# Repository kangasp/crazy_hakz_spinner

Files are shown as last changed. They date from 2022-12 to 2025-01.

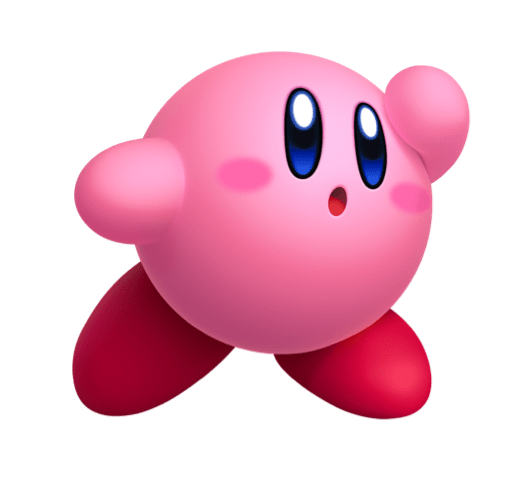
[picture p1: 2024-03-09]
tools/binaries/test_images/kirby.png

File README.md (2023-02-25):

# crazy_hakz_spinner
Spinning LEDs

### Notes from 2-24-23
--------------------------------------------
The footprint for the through beam sensor is wrong - pins 3 and 4 should be switched.
Pin 4 is actually ground / emiter, and pin 3 is actually the collector / vcc.

The through beem should sensor should not be pulled up to VCC - which is 5v.  It should 
be pulled up to 3.3v.

The level shifter should be moved - as it's too close to the mounting bracket... maybe get a bigger one.

Consider moving the positional / counter through beam to the edge.

Consider adding a testpoint header.

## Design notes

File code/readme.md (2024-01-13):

To develop here do these things.

Get the esp-idf framework.  Follow this:
https://docs.espressif.com/projects/esp-idf/en/latest/esp32/get-started/index.html

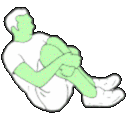
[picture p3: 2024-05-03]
cool_pics/party/png/party7.png

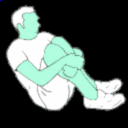
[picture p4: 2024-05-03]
cool_pics/party/bmp/party6.bmp

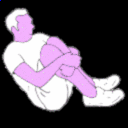
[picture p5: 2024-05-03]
cool_pics/party/bmp/party11.bmp

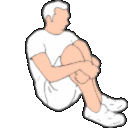
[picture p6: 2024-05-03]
cool_pics/party/png/party1.png

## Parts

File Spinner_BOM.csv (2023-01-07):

Index | Quantity | Part Number | Manufacturer Part Number | Description | Customer Reference | Available | Backorder | Unit Price | Extended Price USD
1 | 1 | 1528-2883-ND | 4172 | HUZZAH32 - ESP32 BREAKOUT BOARD |  | 1 | 0 | 13.50000 | 13.50
2 | 1 | AP63205WU-7DICT-ND | AP63205WU-7 | IC REG BUCK 5V 2A TSOT26 |  | 1 | 0 | 0.91000 | 0.91
3 | 6 | 36-2460-ND | 2460 | BATT HOLDER AA 1 CELL PC PIN |  | 6 | 0 | 1.30000 | 7.80
4 | 1 | EG5810CT-ND | 500ASSP1SM6QE | SWITCH SLIDE SPDT 3A 120V |  | 1 | 0 | 4.90000 | 4.90
5 | 1 | 3565-RS0102YH8CT-ND | RS0102YH8 | IC TRANSLATOR BIDIR SOT23-8 |  | 1 | 0 | 0.67000 | 0.67
6 | 2 | NSI45020AT1GOSCT-ND | NSI45020AT1G | IC LED DRIVER LINEAR SOD-123 |  | 2 | 0 | 0.57000 | 1.14
7 | 3 | RMCF0805JT3K30CT-ND | RMCF0805JT3K30 | RES 3.3K OHM 5% 1/8W 0805 |  | 3 | 0 | 0.10000 | 0.30
8 | 1 | CV201210-4R7KCT-ND | CV201210-4R7K | FIXED IND 4.7UH 30MA 1 OHM SMD |  | 1 | 0 | 0.10000 | 0.10
9 | 1 | 1276-1096-1-ND | CL21A106KOQNNNE | CAP CER 10UF 16V X5R 0805 |  | 1 | 0 | 0.10000 | 0.10
10 | 2 | 1276-6460-1-ND | CL21A226MQQNNNG | CAP CER 22UF 6.3V X5R 0805 |  | 2 | 0 | 0.13000 | 0.26
11 | 50 | 1276-1099-1-ND | CL21B104KACNNNC | CAP CER 0.1UF 25V X7R 0805 |  | 50 | 0 | 0.02020 | 1.01

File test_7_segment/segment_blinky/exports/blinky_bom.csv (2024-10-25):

Comment | Designator | Footprint | JLCPCDB Part #
LED | D7,D6,D42,D36,D24,D14,D26,D50,D8,D15,D59,D22,D55,D39,D44,D48,D9,D46,D11,D4,D49,D38,D53,D54,D21,D56,D17,D28,D45,D43,D47,D27,D60,D57,D30,D31,D35,D34,D32,D58,D37,D12,D2,D33,D51,D19,D29,D52,D13,D5,D41,D23,D18,D25,D16,D40,D20,D3 | SK9822-hakz | C2909059

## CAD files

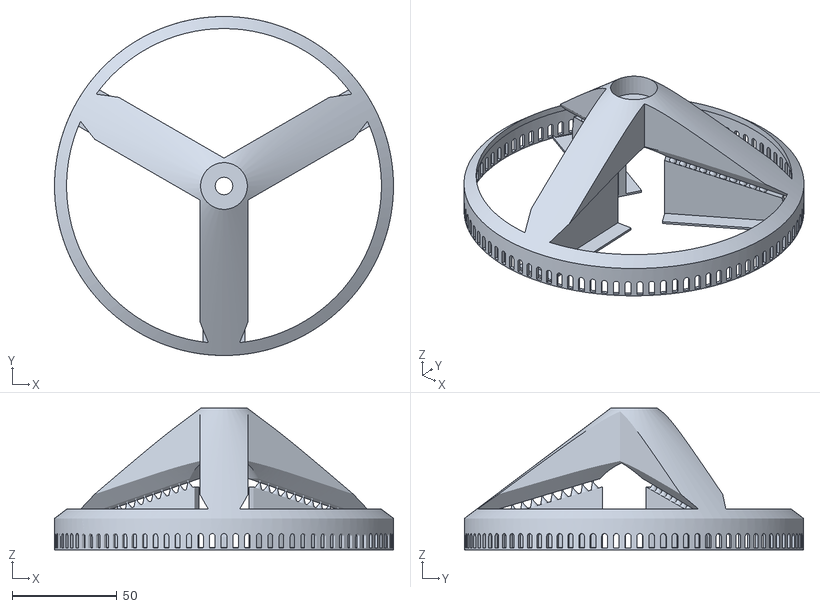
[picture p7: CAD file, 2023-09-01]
stl/crown_w_supports.stl
161.5 x 161.5 x 67.4

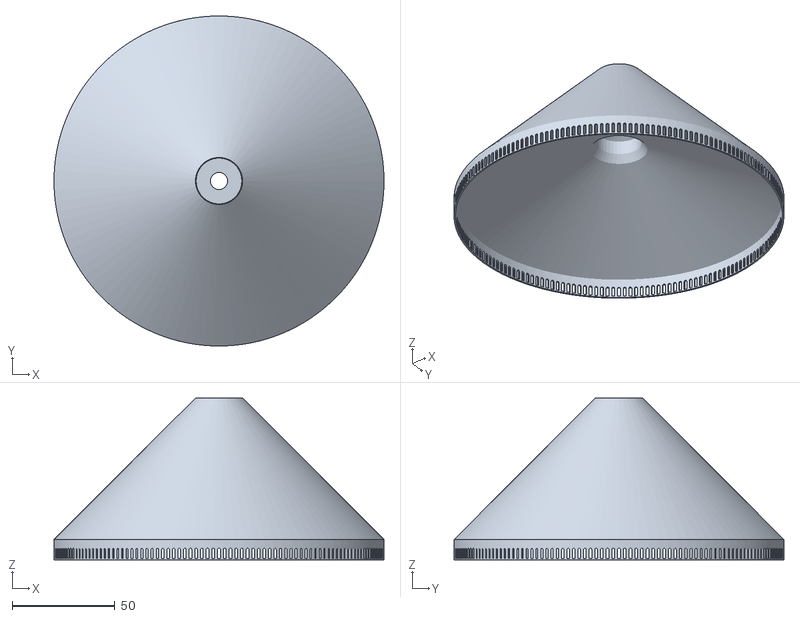
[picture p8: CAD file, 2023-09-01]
stl/crown_01.stl
160.8 x 160.8 x 78.9

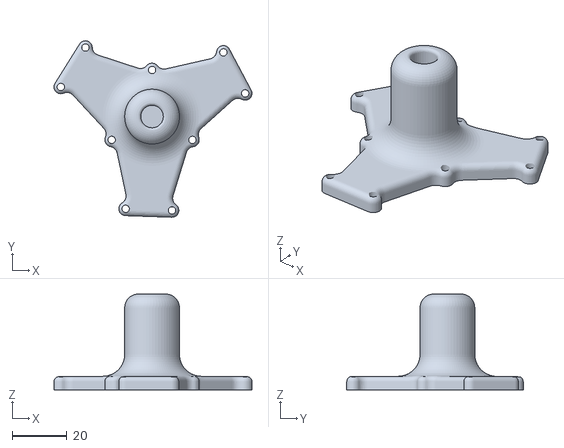
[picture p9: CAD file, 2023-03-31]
stl/rod_bracket_01.stl
72.2 x 64.4 x 35.0

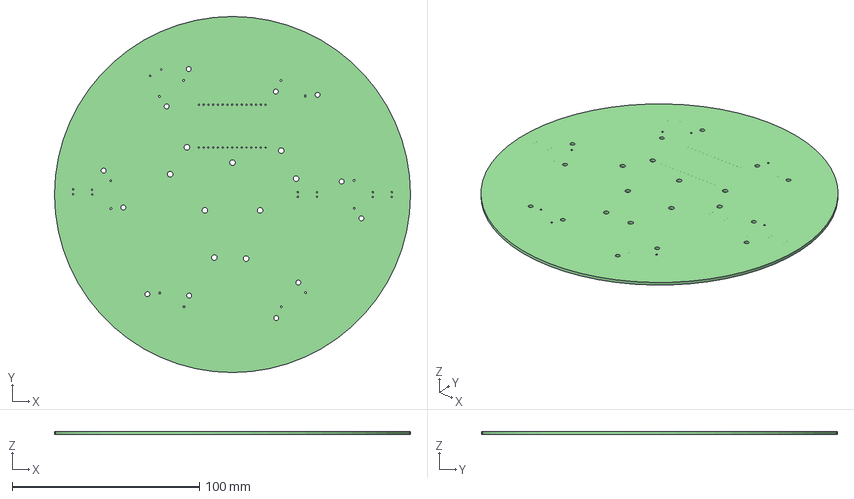
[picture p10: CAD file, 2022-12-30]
stl/spinner.step
190.0 x 190.0 x 1.60 mm

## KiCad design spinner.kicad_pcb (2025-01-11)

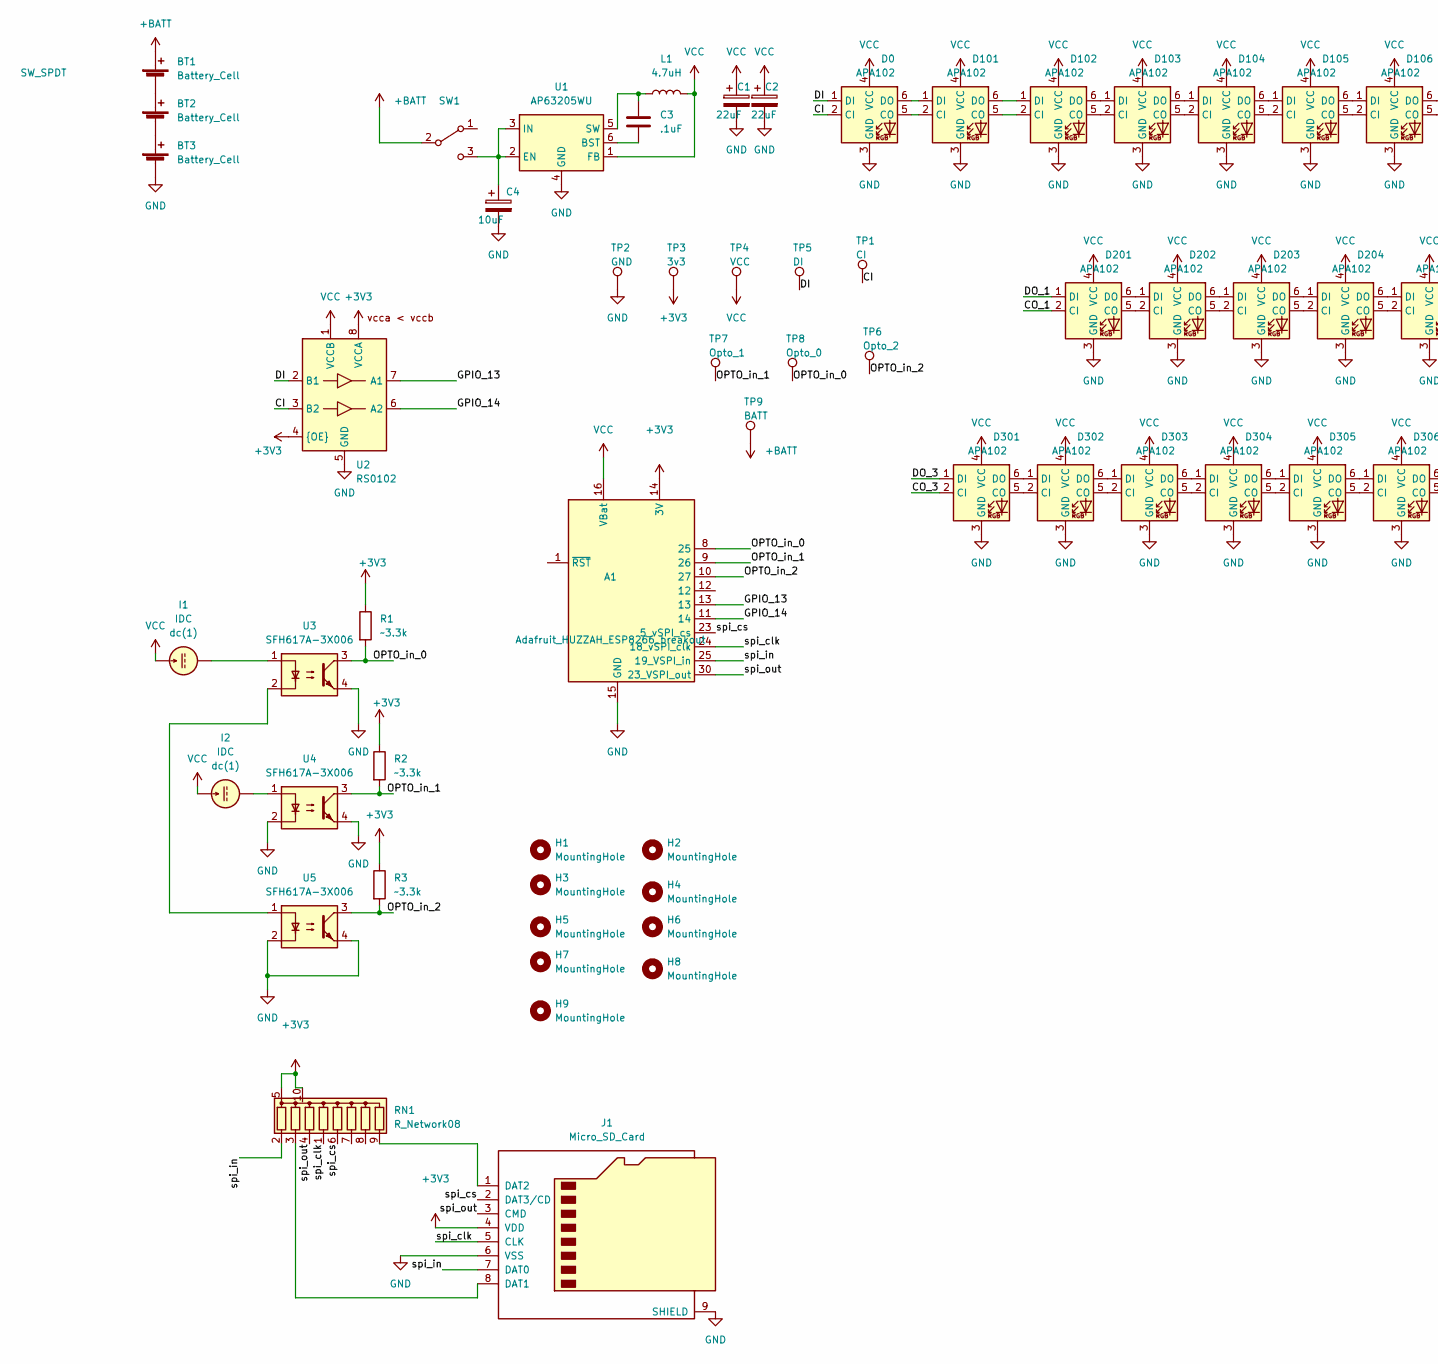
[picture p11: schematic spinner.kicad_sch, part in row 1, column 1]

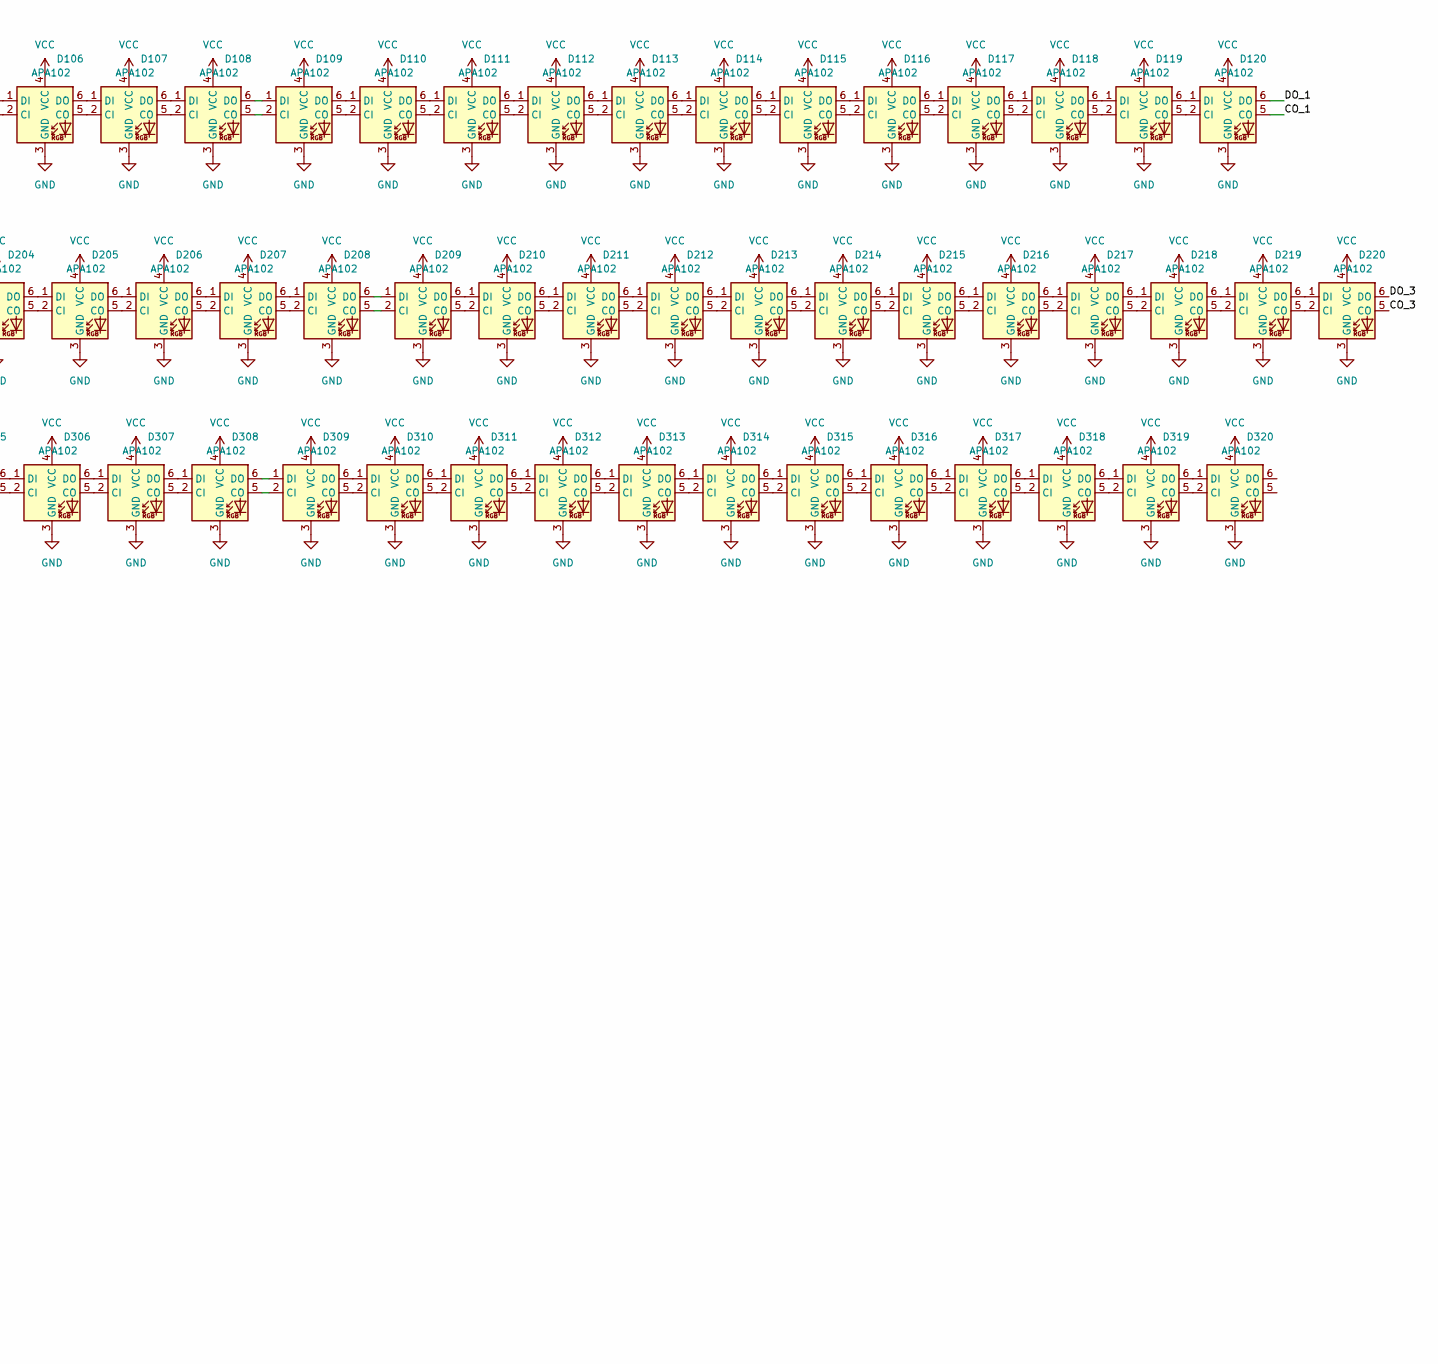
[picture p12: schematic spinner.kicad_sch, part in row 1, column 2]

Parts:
A1: Adafruit_HUZZAH_ESP8266_breakout; huzz_hakz
BT1, BT2, BT3: Battery_Cell; Spinner_BatteryHolder_Keystone_2460_1xAA
C1, C2: 22uF; C_0805_2012Metric_Pad1.18x1.45mm_HandSolder
C3: .1uF; C_0805_2012Metric_Pad1.18x1.45mm_HandSolder
C4: 10uF; C_0805_2012Metric_Pad1.18x1.45mm_HandSolder
D0, D101, D102, D103, D104, D105, D106, D107, D108, D109, D110, D111, D112, D113, D114, D115, D116, D117, D118, D119, D120, D201, D202, D203, D204, D205, D206, D207, D208, D209, D210, D211, D212, D213, D214, D215, D216, D217, D218, D219, D220, D301, D302, D303, D304, D305, D306, D307, D308, D309, D310, D311, D312, D313, D314, D315, D316, D317, D318, D319, D320: APA102; SK9822-hakz
H1, H2, H3, H4, H5, H6, H7, H8, H9: MountingHole; MountingHole_3mm
I1, I2: IDC; D_SOD-123
J1: Micro_SD_Card; microSD_HC_Hirose_DM3AT-SF-PEJM5
L1: 4.7uH; L_0805_2012Metric_Pad1.05x1.20mm_HandSolder
R1, R2, R3: ~3.3k; R_0805_2012Metric_Pad1.20x1.40mm_HandSolder
RN1: R_Network08; R_Array_Convex_5x1206
SW1: SW_SPDT; SW_SPDT_CK-JS102011SAQN
TP1: CI; TestPoint_Pad_D2.5mm
TP2: GND; TestPoint_Pad_D2.5mm
TP3: 3v3; TestPoint_Pad_D2.5mm
TP4: VCC; TestPoint_Pad_D2.5mm
TP5: DI; TestPoint_Pad_D2.5mm
TP6: Opto_2; TestPoint_Pad_D2.5mm
TP7: Opto_1; TestPoint_Pad_D2.5mm
TP8: Opto_0; TestPoint_Pad_D2.5mm
TP9: BATT; TestPoint_Pad_D2.5mm
U1: AP63205WU; TSOT-23-6
U2: RS0102; MSOP-8_3x3mm_P0.65mm
U3, U4: SFH617A-3X006; MULTI_PART_THRU_BEAM
U5: SFH617A-3X006; tcrt1000

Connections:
+3V3: A1.14 (3V), J1.4 (VDD), R1.1, R2.1, R3.1, RN1.5 (common), RN1.10 (common), TP3.1, U2.4 ({OE}), U2.8 (VCCA)
+BATT: BT1.1 (+), SW1.2 (B), TP9.1
/CI: D0.2 (CI), TP1.1, U2.3 (B2)
/CO_1: D120.5 (CO), D201.2 (CI)
/CO_3: D220.5 (CO), D301.2 (CI)
/DI: D0.1 (DI), TP5.1, U2.2 (B1)
/DO_1: D120.6 (DO), D201.1 (DI)
/DO_3: D220.6 (DO), D301.1 (DI)
/GPIO_13: A1.13, U2.7 (A1)
/GPIO_14: A1.11 (14), U2.6 (A2)
/OPTO_in_0: A1.8 (25), R1.2, TP8.1, U3.3
/OPTO_in_1: A1.9 (26), R2.2, TP7.1, U4.3
/OPTO_in_2: A1.10 (27), R3.2, TP6.1, U5.3
/spi_clk: A1.24 (18_vSPI_clk), J1.5 (CLK), RN1.1 (R4)
/spi_cs: A1.23 (5_vSPI_cs), J1.2 (DAT3/CD), RN1.6 (R5)
/spi_in: A1.25 (19_VSPI_in), J1.7 (DAT0), RN1.2 (R1)
/spi_out: A1.30 (23_VSPI_out), J1.3 (CMD), RN1.4 (R3)
GND: A1.15 (GND), BT3.2 (-), C1.2, C2.2, C4.2, D0.3 (GND), D101.3 (GND), D102.3 (GND), D103.3 (GND), D104.3 (GND), D105.3 (GND), D106.3 (GND), D107.3 (GND), D108.3 (GND), D109.3 (GND), D110.3 (GND), D111.3 (GND), D112.3 (GND), D113.3 (GND), D114.3 (GND), D115.3 (GND), D116.3 (GND), D117.3 (GND), D118.3 (GND), D119.3 (GND), D120.3 (GND), D201.3 (GND), D202.3 (GND), D203.3 (GND), D204.3 (GND), D205.3 (GND), D206.3 (GND), D207.3 (GND), D208.3 (GND), D209.3 (GND), D210.3 (GND), D211.3 (GND), D212.3 (GND), D213.3 (GND), D214.3 (GND), D215.3 (GND), D216.3 (GND), D217.3 (GND), D218.3 (GND), D219.3 (GND), D220.3 (GND), D301.3 (GND), D302.3 (GND), D303.3 (GND), D304.3 (GND), D305.3 (GND), D306.3 (GND), D307.3 (GND), D308.3 (GND), D309.3 (GND), D310.3 (GND), D311.3 (GND), D312.3 (GND), D313.3 (GND), D314.3 (GND), D315.3 (GND), D316.3 (GND), D317.3 (GND), D318.3 (GND), D319.3 (GND), D320.3 (GND), J1.6 (VSS), J1.9 (SHIELD), TP2.1, U1.4 (GND), U2.5 (GND), U3.4, U4.2, U4.4, U5.2, U5.4
unnamed: BT1.2 (-), BT2.1 (+)
unnamed: BT2.2 (-), BT3.1 (+)
unnamed: C3.1, L1.1, U1.5 (SW)
unnamed: C3.2, U1.6 (BST)
unnamed: C4.1, SW1.3 (C), U1.2 (EN), U1.3 (IN)
unnamed: D0.5 (CO), D101.2 (CI)
unnamed: D0.6 (DO), D101.1 (DI)
unnamed: D101.5 (CO), D102.2 (CI)
unnamed: D101.6 (DO), D102.1 (DI)
unnamed: D102.5 (CO), D103.2 (CI)
unnamed: D102.6 (DO), D103.1 (DI)
unnamed: D103.5 (CO), D104.2 (CI)
unnamed: D103.6 (DO), D104.1 (DI)
unnamed: D104.5 (CO), D105.2 (CI)
unnamed: D104.6 (DO), D105.1 (DI)
unnamed: D105.5 (CO), D106.2 (CI)
unnamed: D105.6 (DO), D106.1 (DI)
unnamed: D106.5 (CO), D107.2 (CI)
unnamed: D106.6 (DO), D107.1 (DI)
unnamed: D107.5 (CO), D108.2 (CI)
unnamed: D107.6 (DO), D108.1 (DI)
unnamed: D108.5 (CO), D109.2 (CI)
unnamed: D108.6 (DO), D109.1 (DI)
unnamed: D109.5 (CO), D110.2 (CI)
unnamed: D109.6 (DO), D110.1 (DI)
unnamed: D110.5 (CO), D111.2 (CI)
unnamed: D110.6 (DO), D111.1 (DI)
unnamed: D111.5 (CO), D112.2 (CI)
unnamed: D111.6 (DO), D112.1 (DI)
unnamed: D112.5 (CO), D113.2 (CI)
unnamed: D112.6 (DO), D113.1 (DI)
unnamed: D113.5 (CO), D114.2 (CI)
unnamed: D113.6 (DO), D114.1 (DI)
unnamed: D114.5 (CO), D115.2 (CI)
unnamed: D114.6 (DO), D115.1 (DI)
unnamed: D115.5 (CO), D116.2 (CI)
unnamed: D115.6 (DO), D116.1 (DI)
unnamed: D116.5 (CO), D117.2 (CI)
unnamed: D116.6 (DO), D117.1 (DI)
unnamed: D117.5 (CO), D118.2 (CI)
unnamed: D117.6 (DO), D118.1 (DI)
unnamed: D118.5 (CO), D119.2 (CI)
unnamed: D118.6 (DO), D119.1 (DI)
unnamed: D119.5 (CO), D120.2 (CI)
unnamed: D119.6 (DO), D120.1 (DI)
unnamed: D201.5 (CO), D202.2 (CI)
unnamed: D201.6 (DO), D202.1 (DI)
unnamed: D202.5 (CO), D203.2 (CI)
unnamed: D202.6 (DO), D203.1 (DI)
unnamed: D203.5 (CO), D204.2 (CI)
unnamed: D203.6 (DO), D204.1 (DI)
unnamed: D204.5 (CO), D205.2 (CI)
unnamed: D204.6 (DO), D205.1 (DI)
unnamed: D205.5 (CO), D206.2 (CI)
unnamed: D205.6 (DO), D206.1 (DI)
unnamed: D206.5 (CO), D207.2 (CI)
unnamed: D206.6 (DO), D207.1 (DI)
unnamed: D207.5 (CO), D208.2 (CI)
unnamed: D207.6 (DO), D208.1 (DI)
unnamed: D208.5 (CO), D209.2 (CI)
unnamed: D208.6 (DO), D209.1 (DI)
unnamed: D209.5 (CO), D210.2 (CI)
unnamed: D209.6 (DO), D210.1 (DI)
unnamed: D210.5 (CO), D211.2 (CI)
unnamed: D210.6 (DO), D211.1 (DI)
unnamed: D211.5 (CO), D212.2 (CI)
unnamed: D211.6 (DO), D212.1 (DI)
unnamed: D212.5 (CO), D213.2 (CI)
unnamed: D212.6 (DO), D213.1 (DI)
unnamed: D213.5 (CO), D214.2 (CI)
unnamed: D213.6 (DO), D214.1 (DI)
unnamed: D214.5 (CO), D215.2 (CI)
unnamed: D214.6 (DO), D215.1 (DI)
unnamed: D215.5 (CO), D216.2 (CI)
unnamed: D215.6 (DO), D216.1 (DI)
unnamed: D216.5 (CO), D217.2 (CI)
unnamed: D216.6 (DO), D217.1 (DI)
unnamed: D217.5 (CO), D218.2 (CI)
unnamed: D217.6 (DO), D218.1 (DI)
unnamed: D218.5 (CO), D219.2 (CI)
unnamed: D218.6 (DO), D219.1 (DI)
unnamed: D219.5 (CO), D220.2 (CI)
unnamed: D219.6 (DO), D220.1 (DI)
unnamed: D301.5 (CO), D302.2 (CI)
unnamed: D301.6 (DO), D302.1 (DI)
unnamed: D302.5 (CO), D303.2 (CI)
unnamed: D302.6 (DO), D303.1 (DI)
unnamed: D303.5 (CO), D304.2 (CI)
unnamed: D303.6 (DO), D304.1 (DI)
unnamed: D304.5 (CO), D305.2 (CI)
unnamed: D304.6 (DO), D305.1 (DI)
unnamed: D305.5 (CO), D306.2 (CI)
unnamed: D305.6 (DO), D306.1 (DI)
unnamed: D306.5 (CO), D307.2 (CI)
unnamed: D306.6 (DO), D307.1 (DI)
unnamed: D307.5 (CO), D308.2 (CI)
unnamed: D307.6 (DO), D308.1 (DI)
unnamed: D308.5 (CO), D309.2 (CI)
unnamed: D308.6 (DO), D309.1 (DI)
unnamed: D309.5 (CO), D310.2 (CI)
unnamed: D309.6 (DO), D310.1 (DI)
unnamed: D310.5 (CO), D311.2 (CI)
unnamed: D310.6 (DO), D311.1 (DI)
unnamed: D311.5 (CO), D312.2 (CI)
unnamed: D311.6 (DO), D312.1 (DI)
unnamed: D312.5 (CO), D313.2 (CI)
unnamed: D312.6 (DO), D313.1 (DI)
unnamed: D313.5 (CO), D314.2 (CI)
unnamed: D313.6 (DO), D314.1 (DI)
unnamed: D314.5 (CO), D315.2 (CI)
unnamed: D314.6 (DO), D315.1 (DI)
unnamed: D315.5 (CO), D316.2 (CI)
unnamed: D315.6 (DO), D316.1 (DI)
unnamed: D316.5 (CO), D317.2 (CI)
unnamed: D316.6 (DO), D317.1 (DI)
unnamed: D317.5 (CO), D318.2 (CI)
unnamed: D317.6 (DO), D318.1 (DI)
unnamed: D318.5 (CO), D319.2 (CI)
unnamed: D318.6 (DO), D319.1 (DI)
unnamed: D319.5 (CO), D320.2 (CI)
unnamed: D319.6 (DO), D320.1 (DI)
unnamed: I1.2, U3.1
unnamed: I2.2, U4.1
unnamed: J1.1 (DAT2), RN1.9 (R8)
unnamed: J1.8 (DAT1), RN1.3 (R2)
unnamed: U3.2, U5.1
VCC: A1.16 (VBat), C1.1, C2.1, D0.4 (VCC), D101.4 (VCC), D102.4 (VCC), D103.4 (VCC), D104.4 (VCC), D105.4 (VCC), D106.4 (VCC), D107.4 (VCC), D108.4 (VCC), D109.4 (VCC), D110.4 (VCC), D111.4 (VCC), D112.4 (VCC), D113.4 (VCC), D114.4 (VCC), D115.4 (VCC), D116.4 (VCC), D117.4 (VCC), D118.4 (VCC), D119.4 (VCC), D120.4 (VCC), D201.4 (VCC), D202.4 (VCC), D203.4 (VCC), D204.4 (VCC), D205.4 (VCC), D206.4 (VCC), D207.4 (VCC), D208.4 (VCC), D209.4 (VCC), D210.4 (VCC), D211.4 (VCC), D212.4 (VCC), D213.4 (VCC), D214.4 (VCC), D215.4 (VCC), D216.4 (VCC), D217.4 (VCC), D218.4 (VCC), D219.4 (VCC), D220.4 (VCC), D301.4 (VCC), D302.4 (VCC), D303.4 (VCC), D304.4 (VCC), D305.4 (VCC), D306.4 (VCC), D307.4 (VCC), D308.4 (VCC), D309.4 (VCC), D310.4 (VCC), D311.4 (VCC), D312.4 (VCC), D313.4 (VCC), D314.4 (VCC), D315.4 (VCC), D316.4 (VCC), D317.4 (VCC), D318.4 (VCC), D319.4 (VCC), D320.4 (VCC), I1.1, I2.1, L1.2, TP4.1, U1.1 (FB), U2.1 (VCCB)

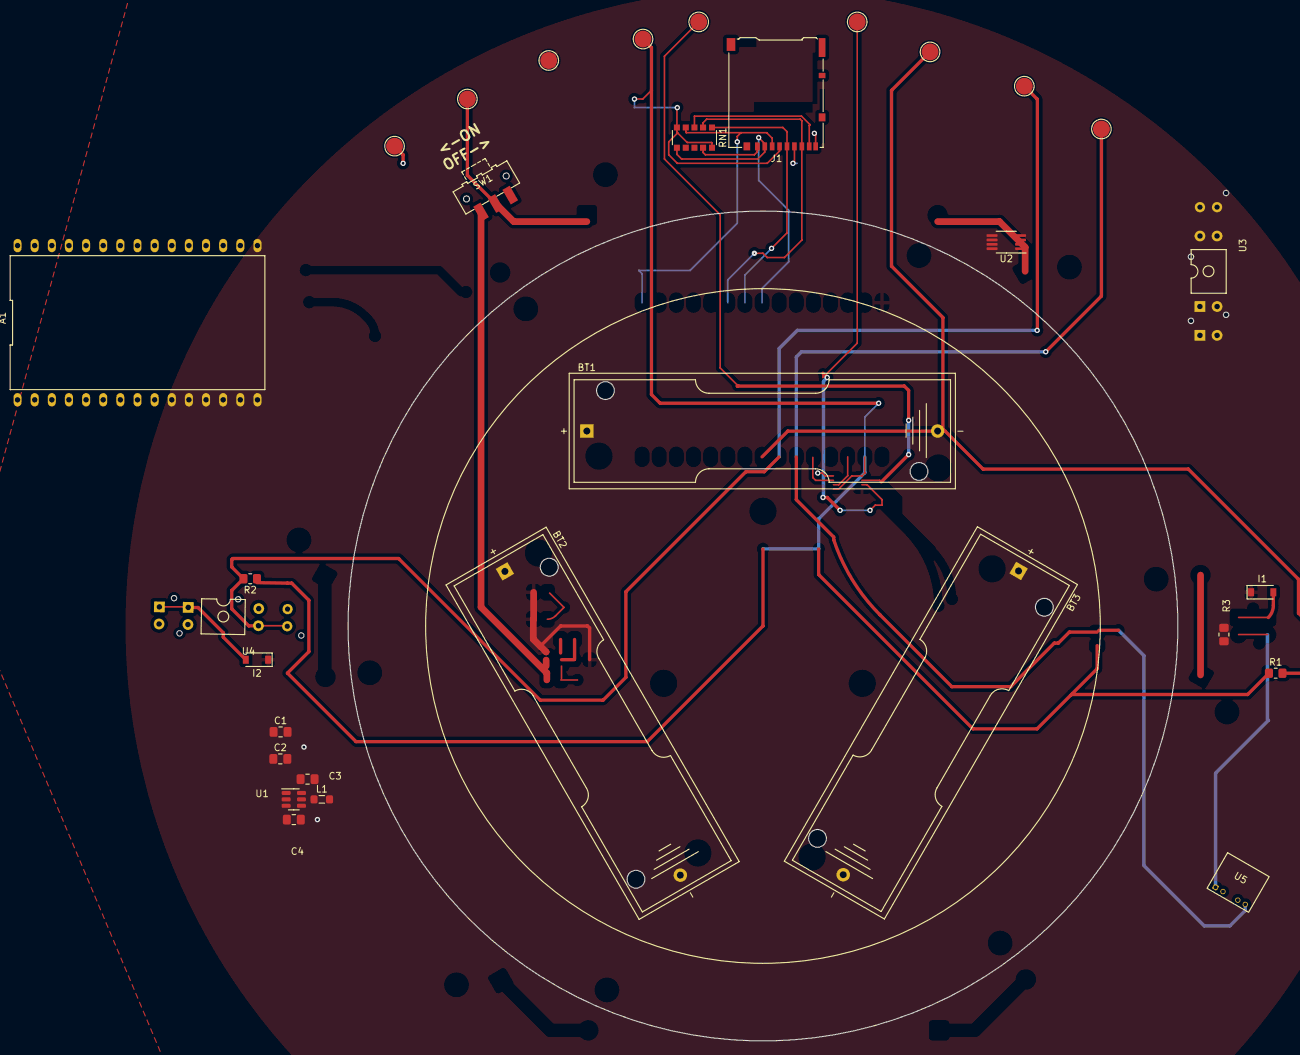
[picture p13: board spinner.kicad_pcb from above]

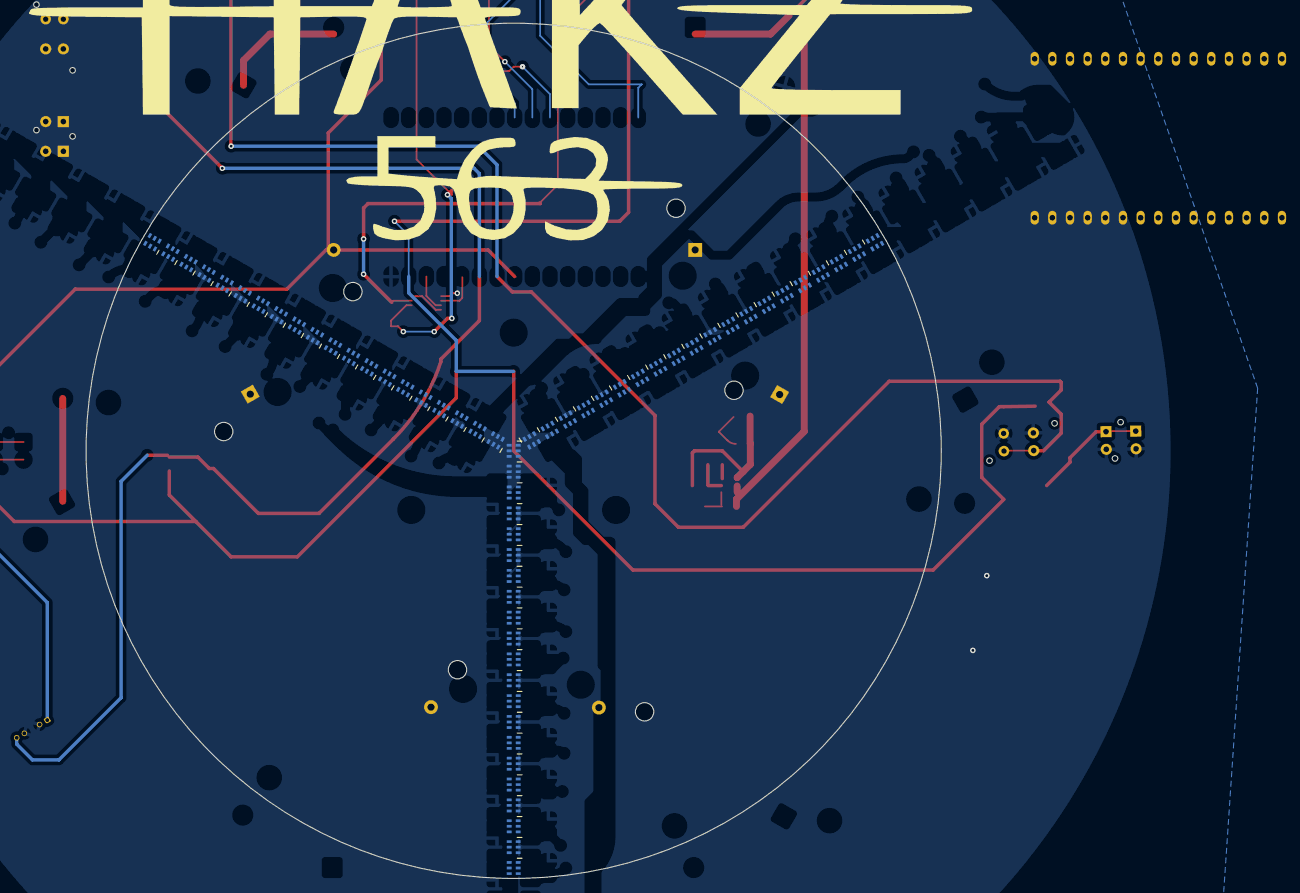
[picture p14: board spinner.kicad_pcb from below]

Board: 2 copper layers, 92 parts (61 on the bottom side), 145 nets.

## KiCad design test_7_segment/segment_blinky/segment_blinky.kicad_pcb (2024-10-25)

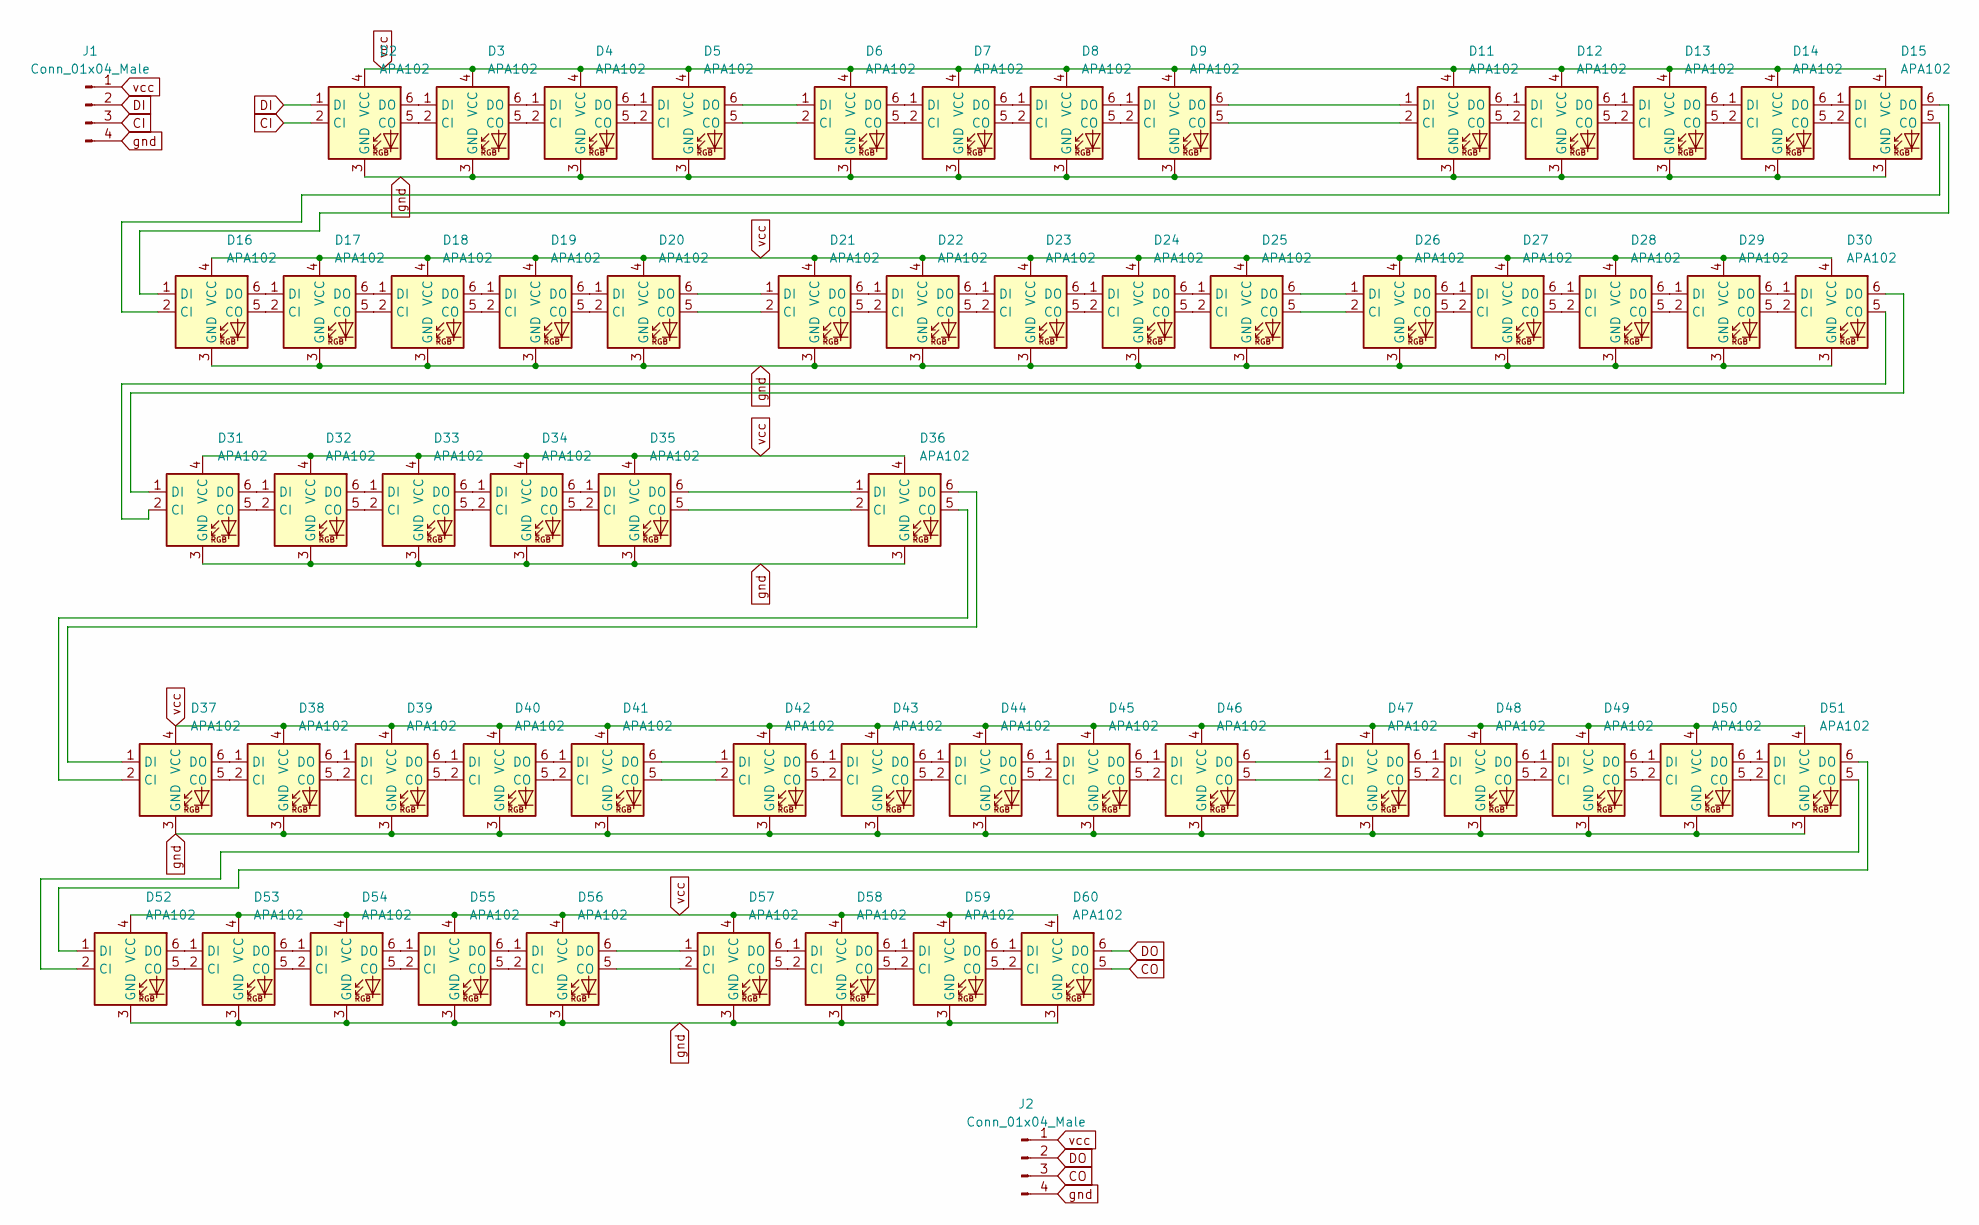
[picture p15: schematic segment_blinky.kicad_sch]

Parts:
D2, D3, D4, D5, D6, D7, D8, D9, D11, D12, D13, D14, D15, D16, D17, D18, D19, D20, D21, D22, D23, D24, D25, D26, D27, D28, D29, D30, D31, D32, D33, D34, D35, D36, D37, D38, D39, D40, D41, D42, D43, D44, D45, D46, D47, D48, D49, D50, D51, D52, D53, D54, D55, D56, D57, D58, D59, D60: APA102; SK9822-hakz
J1, J2: Conn_01x04_Male; PinHeader_1x04_P2.54mm_Vertical

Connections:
CI: D2.2 (CI), J1.3
CO: D60.5 (CO), J2.3
DI: D2.1 (DI), J1.2
DO: D60.6 (DO), J2.2
unnamed: D2.5 (CO), D3.2 (CI)
unnamed: D2.6 (DO), D3.1 (DI)
unnamed: D3.5 (CO), D4.2 (CI)
unnamed: D3.6 (DO), D4.1 (DI)
unnamed: D4.5 (CO), D5.2 (CI)
unnamed: D4.6 (DO), D5.1 (DI)
unnamed: D5.5 (CO), D6.2 (CI)
unnamed: D5.6 (DO), D6.1 (DI)
unnamed: D6.5 (CO), D7.2 (CI)
unnamed: D6.6 (DO), D7.1 (DI)
unnamed: D7.5 (CO), D8.2 (CI)
unnamed: D7.6 (DO), D8.1 (DI)
unnamed: D8.5 (CO), D9.2 (CI)
unnamed: D8.6 (DO), D9.1 (DI)
unnamed: D9.5 (CO), D11.2 (CI)
unnamed: D9.6 (DO), D11.1 (DI)
unnamed: D11.5 (CO), D12.2 (CI)
unnamed: D11.6 (DO), D12.1 (DI)
unnamed: D12.5 (CO), D13.2 (CI)
unnamed: D12.6 (DO), D13.1 (DI)
unnamed: D13.5 (CO), D14.2 (CI)
unnamed: D13.6 (DO), D14.1 (DI)
unnamed: D14.5 (CO), D15.2 (CI)
unnamed: D14.6 (DO), D15.1 (DI)
unnamed: D15.5 (CO), D16.2 (CI)
unnamed: D15.6 (DO), D16.1 (DI)
unnamed: D16.5 (CO), D17.2 (CI)
unnamed: D16.6 (DO), D17.1 (DI)
unnamed: D17.5 (CO), D18.2 (CI)
unnamed: D17.6 (DO), D18.1 (DI)
unnamed: D18.5 (CO), D19.2 (CI)
unnamed: D18.6 (DO), D19.1 (DI)
unnamed: D19.5 (CO), D20.2 (CI)
unnamed: D19.6 (DO), D20.1 (DI)
unnamed: D20.5 (CO), D21.2 (CI)
unnamed: D20.6 (DO), D21.1 (DI)
unnamed: D21.5 (CO), D22.2 (CI)
unnamed: D21.6 (DO), D22.1 (DI)
unnamed: D22.5 (CO), D23.2 (CI)
unnamed: D22.6 (DO), D23.1 (DI)
unnamed: D23.5 (CO), D24.2 (CI)
unnamed: D23.6 (DO), D24.1 (DI)
unnamed: D24.5 (CO), D25.2 (CI)
unnamed: D24.6 (DO), D25.1 (DI)
unnamed: D25.5 (CO), D26.2 (CI)
unnamed: D25.6 (DO), D26.1 (DI)
unnamed: D26.5 (CO), D27.2 (CI)
unnamed: D26.6 (DO), D27.1 (DI)
unnamed: D27.5 (CO), D28.2 (CI)
unnamed: D27.6 (DO), D28.1 (DI)
unnamed: D28.5 (CO), D29.2 (CI)
unnamed: D28.6 (DO), D29.1 (DI)
unnamed: D29.5 (CO), D30.2 (CI)
unnamed: D29.6 (DO), D30.1 (DI)
unnamed: D30.5 (CO), D31.2 (CI)
unnamed: D30.6 (DO), D31.1 (DI)
unnamed: D31.5 (CO), D32.2 (CI)
unnamed: D31.6 (DO), D32.1 (DI)
unnamed: D32.5 (CO), D33.2 (CI)
unnamed: D32.6 (DO), D33.1 (DI)
unnamed: D33.5 (CO), D34.2 (CI)
unnamed: D33.6 (DO), D34.1 (DI)
unnamed: D34.5 (CO), D35.2 (CI)
unnamed: D34.6 (DO), D35.1 (DI)
unnamed: D35.5 (CO), D36.2 (CI)
unnamed: D35.6 (DO), D36.1 (DI)
unnamed: D36.5 (CO), D37.2 (CI)
unnamed: D36.6 (DO), D37.1 (DI)
unnamed: D37.5 (CO), D38.2 (CI)
unnamed: D37.6 (DO), D38.1 (DI)
unnamed: D38.5 (CO), D39.2 (CI)
unnamed: D38.6 (DO), D39.1 (DI)
unnamed: D39.5 (CO), D40.2 (CI)
unnamed: D39.6 (DO), D40.1 (DI)
unnamed: D40.5 (CO), D41.2 (CI)
unnamed: D40.6 (DO), D41.1 (DI)
unnamed: D41.5 (CO), D42.2 (CI)
unnamed: D41.6 (DO), D42.1 (DI)
unnamed: D42.5 (CO), D43.2 (CI)
unnamed: D42.6 (DO), D43.1 (DI)
unnamed: D43.5 (CO), D44.2 (CI)
unnamed: D43.6 (DO), D44.1 (DI)
unnamed: D44.5 (CO), D45.2 (CI)
unnamed: D44.6 (DO), D45.1 (DI)
unnamed: D45.5 (CO), D46.2 (CI)
unnamed: D45.6 (DO), D46.1 (DI)
unnamed: D46.5 (CO), D47.2 (CI)
unnamed: D46.6 (DO), D47.1 (DI)
unnamed: D47.5 (CO), D48.2 (CI)
unnamed: D47.6 (DO), D48.1 (DI)
unnamed: D48.5 (CO), D49.2 (CI)
unnamed: D48.6 (DO), D49.1 (DI)
unnamed: D49.5 (CO), D50.2 (CI)
unnamed: D49.6 (DO), D50.1 (DI)
unnamed: D50.5 (CO), D51.2 (CI)
unnamed: D50.6 (DO), D51.1 (DI)
unnamed: D51.5 (CO), D52.2 (CI)
unnamed: D51.6 (DO), D52.1 (DI)
unnamed: D52.5 (CO), D53.2 (CI)
unnamed: D52.6 (DO), D53.1 (DI)
unnamed: D53.5 (CO), D54.2 (CI)
unnamed: D53.6 (DO), D54.1 (DI)
unnamed: D54.5 (CO), D55.2 (CI)
unnamed: D54.6 (DO), D55.1 (DI)
unnamed: D55.5 (CO), D56.2 (CI)
unnamed: D55.6 (DO), D56.1 (DI)
unnamed: D56.5 (CO), D57.2 (CI)
unnamed: D56.6 (DO), D57.1 (DI)
unnamed: D57.5 (CO), D58.2 (CI)
unnamed: D57.6 (DO), D58.1 (DI)
unnamed: D58.5 (CO), D59.2 (CI)
unnamed: D58.6 (DO), D59.1 (DI)
unnamed: D59.5 (CO), D60.2 (CI)
unnamed: D59.6 (DO), D60.1 (DI)
gnd: D2.3 (GND), D3.3 (GND), D4.3 (GND), D5.3 (GND), D6.3 (GND), D7.3 (GND), D8.3 (GND), D9.3 (GND), D11.3 (GND), D12.3 (GND), D13.3 (GND), D14.3 (GND), D15.3 (GND), D16.3 (GND), D17.3 (GND), D18.3 (GND), D19.3 (GND), D20.3 (GND), D21.3 (GND), D22.3 (GND), D23.3 (GND), D24.3 (GND), D25.3 (GND), D26.3 (GND), D27.3 (GND), D28.3 (GND), D29.3 (GND), D30.3 (GND), D31.3 (GND), D32.3 (GND), D33.3 (GND), D34.3 (GND), D35.3 (GND), D36.3 (GND), D37.3 (GND), D38.3 (GND), D39.3 (GND), D40.3 (GND), D41.3 (GND), D42.3 (GND), D43.3 (GND), D44.3 (GND), D45.3 (GND), D46.3 (GND), D47.3 (GND), D48.3 (GND), D49.3 (GND), D50.3 (GND), D51.3 (GND), D52.3 (GND), D53.3 (GND), D54.3 (GND), D55.3 (GND), D56.3 (GND), D57.3 (GND), D58.3 (GND), D59.3 (GND), D60.3 (GND), J1.4, J2.4
vcc: D2.4 (VCC), D3.4 (VCC), D4.4 (VCC), D5.4 (VCC), D6.4 (VCC), D7.4 (VCC), D8.4 (VCC), D9.4 (VCC), D11.4 (VCC), D12.4 (VCC), D13.4 (VCC), D14.4 (VCC), D15.4 (VCC), D16.4 (VCC), D17.4 (VCC), D18.4 (VCC), D19.4 (VCC), D20.4 (VCC), D21.4 (VCC), D22.4 (VCC), D23.4 (VCC), D24.4 (VCC), D25.4 (VCC), D26.4 (VCC), D27.4 (VCC), D28.4 (VCC), D29.4 (VCC), D30.4 (VCC), D31.4 (VCC), D32.4 (VCC), D33.4 (VCC), D34.4 (VCC), D35.4 (VCC), D36.4 (VCC), D37.4 (VCC), D38.4 (VCC), D39.4 (VCC), D40.4 (VCC), D41.4 (VCC), D42.4 (VCC), D43.4 (VCC), D44.4 (VCC), D45.4 (VCC), D46.4 (VCC), D47.4 (VCC), D48.4 (VCC), D49.4 (VCC), D50.4 (VCC), D51.4 (VCC), D52.4 (VCC), D53.4 (VCC), D54.4 (VCC), D55.4 (VCC), D56.4 (VCC), D57.4 (VCC), D58.4 (VCC), D59.4 (VCC), D60.4 (VCC), J1.1, J2.1

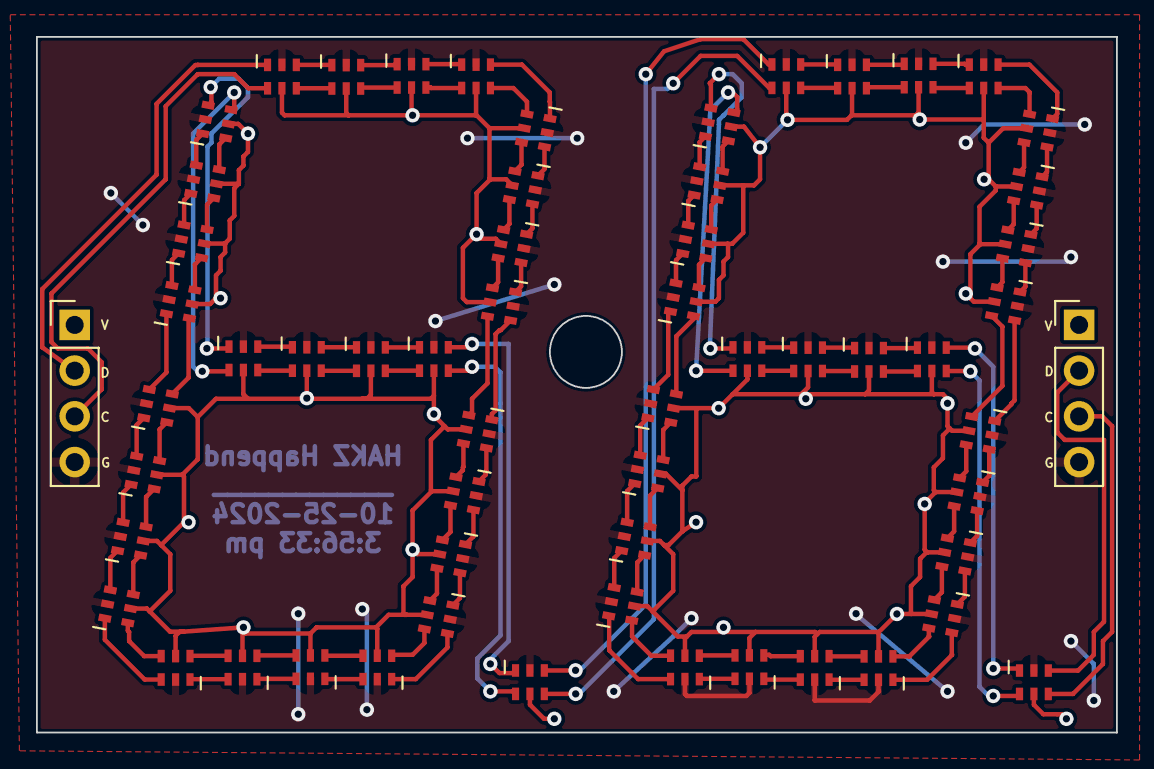
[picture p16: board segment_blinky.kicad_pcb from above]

Board: 2 copper layers, 60.0 x 38.6 mm, 60 parts (0 on the bottom side), 120 nets.

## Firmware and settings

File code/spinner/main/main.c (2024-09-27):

#include <stdio.h>
#include <string.h>
#include "freertos/FreeRTOS.h"
#include "freertos/task.h"
#include "esp_system.h"
//#include "hal/spi_types.h"
#include "esp_spi_flash.h"

#include "driver/spi_master.h"
#include "driver/gpio.h"
// #include "driver/pulse_cnt.h"  This is for newer framework... 5+ ??

#include "rotary_encoder.h"
#include "all_things.h"


#define LED_NUM  45
#define BUF_SZ  ((3 + LED_NUM) * sizeof(uint32_t))  // 1 uint32 for start, 2 uint32 for end
#define RGBL(r,g,b,lum) ((((gamma8[g]) & 0xFF)<<24) | (((gamma8[b]) & 0xFF)<<16) | (((gamma8[r]) & 0xFF)<<8) | (((lum) & 0xFF) | 0xE0)<<0  ) 
//#define HSPI_HOST   SPI2_HOST
//#define VSPI_HOST   SPI3_HOST
#define LED_HOST HSPI_HOST
    // host = HSPIC_HOST;
    // host = VSPIC_HOST;
#define PIN_NUM_MISO -1
#define PIN_NUM_MOSI 13
#define PIN_NUM_CLK  14
//#define PIN_NUM_MOSI 23
//#define PIN_NUM_CLK  18
// #define PIN_NUM_MOSI 30
// #define PIN_NUM_CLK  24
#define PIN_NUM_CS   -1
#define PIN_A GPIO_NUM_25
#define PIN_B GPIO_NUM_26
#define PIN_Z GPIO_NUM_27


volatile static uint8_t     zero_me = 0;
static rotary_encoder_t    *s_encoder;


const uint8_t gamma8[] = {
    0,  0,  0,  0,  0,  0,  0,  0,  0,  0,  0,  0,  0,  0,  0,  0,
    0,  0,  0,  0,  0,  0,  0,  0,  0,  0,  0,  0,  1,  1,  1,  1,
    1,  1,  1,  1,  1,  1,  1,  1,  1,  2,  2,  2,  2,  2,  2,  2,
    2,  3,  3,  3,  3,  3,  3,  3,  4,  4,  4,  4,  4,  5,  5,  5,
    5,  6,  6,  6,  6,  7,  7,  7,  7,  8,  8,  8,  9,  9,  9, 10,
   10, 10, 11, 11, 11, 12, 12, 13, 13, 13, 14, 14, 15, 15, 16, 16,
   17, 17, 18, 18, 19, 19, 20, 20, 21, 21, 22, 22, 23, 24, 24, 25,
   25, 26, 27, 27, 28, 29, 29, 30, 31, 32, 32, 33, 34, 35, 35, 36,
   37, 38, 39, 39, 40, 41, 42, 43, 44, 45, 46, 47, 48, 49, 50, 50,
   51, 52, 54, 55, 56, 57, 58, 59, 60, 61, 62, 63, 64, 66, 67, 68,
   69, 70, 72, 73, 74, 75, 77, 78, 79, 81, 82, 83, 85, 86, 87, 89,
   90, 92, 93, 95, 96, 98, 99,101,102,104,105,107,109,110,112,114,
  115,117,119,120,122,124,126,127,129,131,133,135,137,138,140,142,
  144,146,148,150,152,154,156,158,160,162,164,167,169,171,173,175,
  177,180,182,184,186,189,191,193,196,198,200,203,205,208,210,213,
  215,218,220,223,225,228,231,233,236,239,241,244,247,249,252,255 };






// static rgb_t g_buf[360][15] = {
// 0
// };

void setup_zeroing_isr();
static inline void IRAM_ATTR zero_isr_handler(void* arg);
static int init_led_spi(spi_device_handle_t *spi);

static int init_led_spi(spi_device_handle_t *spi)
{
    esp_err_t ret;
    spi_bus_config_t buscfg={
        .miso_io_num=-1,
        .mosi_io_num=PIN_NUM_MOSI,
        .sclk_io_num=PIN_NUM_CLK,
        .quadwp_io_num=-1,
        .quadhd_io_num=-1,
        .max_transfer_sz=BUF_SZ
    };
    spi_device_interface_config_t devcfg={
        .clock_speed_hz=SPI_MASTER_FREQ_10M, //      SPI_MASTER_FREQ_40M, //     20*1000*1000,
        .mode=0, // 3, SPICOMMON_BUSFLAG_DUAL   SPI_TRANS_MODE_DIO                                //SPI mode 0
        .spics_io_num=-1,                       //CS pin
        .queue_size=1,                          //We want to be able to queue 7 transactions at a time
        //.pre_cb=lcd_spi_pre_transfer_callback,  //Specify pre-transfer callback to handle D/C line
    };

    ret=spi_bus_initialize(LED_HOST, &buscfg, SPI_DMA_CH_AUTO);
    printf("spi_bus_init, ret:  %d\n", ret );
    ret=spi_bus_add_device(LED_HOST, &devcfg, spi);
    printf("spi_bus_add_device, ret:  %d\n", ret );
	return ESP_OK;
}

void update_buf(uint32_t *buf, int p)
    {
    #define LUM 0xe5
    uint8_t r, g, b, i, l;
    int s;
    #ifdef WORKEDDD
        memcpy( &buf[1],    &g_buf[p][0], sizeof(uint32_t)*15 );
        memcpy( &buf[1+15], &g_buf[(p+120) % 360][0], sizeof(uint32_t)*15 );
        memcpy( &buf[1+30], &g_buf[(p+240)%360][0], sizeof(uint32_t)*15 );
    #endif
    s = 0/*  */;
    // printf("Hello P: %d\n", p);
    for(i=0; i<LED_NUM; i++)
        {
        if( i >=0 && i < 15 )
            {
            s = p;
            }
        else if( i >=15 && i < 30 )
            {
            s = (p+240) % 360;
            }
        else if( i >=30 && i < 45 )
            {
            s = (p+120) % 360;
            }
        l = i % 15; 
        r = g_buf[s][l].r;
        g = g_buf[s][l].g;
        b = g_buf[s][l].b;

        buf[i+1] = RGBL(r,g,b,LUM);

        if ( i == 20 )
            buf[i+1] = RGBL(0,0,0,LUM);

        // if( p == 1)
        //     buf[i+1] = RGBL(0x0,0x55,0x55,LUM);
        // else
        //     buf[i+1] = RGBL(0x0,0x00,0x00,LUM);
        
        }
    }


#ifdef USE_THE_NEWER_PCNT_DRIVER
void setup_encoder(pcnt_unit_handle_t *pcnt_unit)
    {
    ESP_LOGI(TAG, "install pcnt unit");
    pcnt_unit_config_t unit_config = {
        .high_limit = 360,
        .low_limit = 0,
    };
    ESP_ERROR_CHECK(pcnt_new_unit(&unit_config, pcnt_unit));

    ESP_LOGI(TAG, "set glitch filter");
    pcnt_glitch_filter_config_t filter_config = {
        .max_glitch_ns = 1000,
    };
    ESP_ERROR_CHECK(pcnt_unit_set_glitch_filter(*pcnt_unit, &filter_config));

    ESP_LOGI(TAG, "install pcnt channels");
    pcnt_chan_config_t chan_a_config = {
        .edge_gpio_num = PIN_A,
        .level_gpio_num = PIN_B,
    };
    pcnt_channel_handle_t pcnt_chan_a = NULL;
    ESP_ERROR_CHECK(pcnt_new_channel(*pcnt_unit, &chan_a_config, &pcnt_chan_a));
    pcnt_chan_config_t chan_b_config = {
        .edge_gpio_num = PIN_B,
        .level_gpio_num = PIN_A,
    };
    pcnt_channel_handle_t pcnt_chan_b = NULL;
    ESP_ERROR_CHECK(pcnt_new_channel(*pcnt_unit, &chan_b_config, &pcnt_chan_b));

    ESP_LOGI(TAG, "set edge and level actions for pcnt channels");
    ESP_ERROR_CHECK(pcnt_channel_set_edge_action(pcnt_chan_a, PCNT_CHANNEL_EDGE_ACTION_DECREASE, PCNT_CHANNEL_EDGE_ACTION_INCREASE));
    ESP_ERROR_CHECK(pcnt_channel_set_level_action(pcnt_chan_a, PCNT_CHANNEL_LEVEL_ACTION_KEEP, PCNT_CHANNEL_LEVEL_ACTION_INVERSE));
    ESP_ERROR_CHECK(pcnt_channel_set_edge_action(pcnt_chan_b, PCNT_CHANNEL_EDGE_ACTION_INCREASE, PCNT_CHANNEL_EDGE_ACTION_DECREASE));
    ESP_ERROR_CHECK(pcnt_channel_set_level_action(pcnt_chan_b, PCNT_CHANNEL_LEVEL_ACTION_KEEP, PCNT_CHANNEL_LEVEL_ACTION_INVERSE));
}
#endif



rotary_encoder_t* setup_encoder()
{
    rotary_encoder_t* encoder = NULL;
    uint32_t pcnt_unit = 0;
    rotary_encoder_config_t config = ROTARY_ENCODER_DEFAULT_CONFIG((rotary_encoder_dev_t)pcnt_unit, PIN_A, PIN_B);
    ESP_ERROR_CHECK(rotary_encoder_new_ec11(&config, &encoder));
    // Filter out glitch (1us)
    ESP_ERROR_CHECK(encoder->set_glitch_filter(encoder, 0));
    // Start encoder
    ESP_ERROR_CHECK(encoder->start(encoder));
    return encoder;
}

static char s_home[1024*1];
static ssize_t s_home_sz;

char * get_home()
    {
    return s_home;
    }
ssize_t get_home_sz()
{
    return s_home_sz;
}

void app_main(void)
{
    esp_err_t ret;
    spi_device_handle_t spi;
    uint32_t *buf;
    // pcnt_unit_handle_t pcnt_unit;
    size_t size = BUF_SZ;
    spi_transaction_t t = {0};

    int                  s_i;
    int                  i;
	FILE      *f;
	size_t	  ret_sz;
	char     pth[164];

    setup_zeroing_isr();
    ota_server( NULL );

    memset(s_home, 0, sizeof(s_home));
    // printf("opening File!\n");
    if( sd_open() == ESP_OK )
        {
        read_pic( MOUNT_POINT"/new_pic.bin", g_buf, G_BUF_SZ );
        sd_close();
        }
    // setup_encoder(&pcnt_unit);
    s_encoder = setup_encoder();
    ret = init_led_spi(&spi);
	buf = (uint32_t*)heap_caps_malloc(size, MALLOC_CAP_DMA | MALLOC_CAP_32BIT);
    memset(buf, 0, sizeof(*buf));

    for( i = 0; i < LED_NUM+3; i++ )
    {
        buf[i] = 0x0;
    }


    buf[0] = 0x00000000;
    buf[LED_NUM+1] = 0xFFFFFFFF;
    buf[LED_NUM+2] = 0xFFFFFFFF;
    t.tx_buffer = buf;
    t.length = BUF_SZ * 8;


    // for( i = 0; i < 0; i++ )
    // {
    // for( int j = 0; j < 15; j++ )
    //     {
    //     g_buf[i][j].r = (g_stuff[i/6][j] >> 16) & 0xFF;
    //     g_buf[i][j].g = (g_stuff[i/6][j] >> 8) & 0xFF;
    //     g_buf[i][j].b = (g_stuff[i/6][j] >> 0) & 0xFF;
    //     }
    // }


// esp_err_t spi_device_transmit(spi_device_handle_t handle, spi_transaction_t *trans_desc);
    printf("Hello, Tester!\n");
    printf("rgb:  0x%02X, 0x%02X, 0x%02X\n", g_buf[0][0].r,  g_buf[0][0].g,  g_buf[0][0].b);
    i = 0;

    TaskHandle_t myTaskHandle2 = NULL;
    xTaskCreatePinnedToCore(frame_buffer, "FRAMEBUFFER!!", 4096, NULL,10, &myTaskHandle2, 1);
    i = s_encoder->get_counter_value(s_encoder);
    s_i = i%360;
    while( 1 )
        {
            /*
            spoke    radial
            -------------------
            1        90, 346   
            2       210, 106
            3       330, 226
            */
        i = s_encoder->get_counter_value(s_encoder);
        if( zero_me )
            {
            s_i = i;
            zero_me = 0;
            }

        i -= s_i;

    // pcnt_counter_clear(ec11->pcnt_unit);

        while( i < 0 ) i = i+360;
        i = i%360;
        update_buf(buf, i);
        ret = spi_device_transmit( spi, &t );
        ets_delay_us(5);
        vTaskDelay(0);

        }
}

void frame_buffer(void* args)
{
    char pth[64];
    int i = 1;
    // sd_open();
    while(1)
    {
        snprintf( pth, sizeof(pth), MOUNT_POINT"/party/%d.bin", i++ );
        if( 1 ) // read_pic( pth, g_buf, G_BUF_SZ ) )
            {
            sleepy_time(10);
            }
        else
            {
            i = 1;
            }
    }
    // sd_close();
}


static inline void IRAM_ATTR zero_isr_handler(void* arg) {
    zero_me = 1;
}

void setup_zeroing_isr() {
    gpio_pad_select_gpio(PIN_Z);
    gpio_set_direction(PIN_Z, GPIO_MODE_INPUT);
    // gpio_pulldown_en(PIN_Z);
    gpio_set_intr_type(PIN_Z, GPIO_INTR_POSEDGE);

    gpio_install_isr_service(0);
    gpio_isr_handler_add(PIN_Z, zero_isr_handler, NULL);
    }

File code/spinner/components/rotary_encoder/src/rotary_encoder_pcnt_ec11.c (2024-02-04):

// Copyright 2020 Espressif Systems (Shanghai) PTE LTD
//
// Licensed under the Apache License, Version 2.0 (the "License");
// you may not use this file except in compliance with the License.
// You may obtain a copy of the License at
//
//     http://www.apache.org/licenses/LICENSE-2.0
//
// Unless required by applicable law or agreed to in writing, software
// distributed under the License is distributed on an "AS IS" BASIS,
// WITHOUT WARRANTIES OR CONDITIONS OF ANY KIND, either express or implied.
// See the License for the specific language governing permissions and
// limitations under the License.
#include <stdlib.h>
#include <string.h>
#include <sys/cdefs.h>
#include "esp_compiler.h"
#include "esp_log.h"
#include "driver/pcnt.h"
#include "sys/lock.h"
#include "hal/pcnt_hal.h"
#include "rotary_encoder.h"

static const char *TAG = "rotary_encoder";

#define ROTARY_CHECK(a, msg, tag, ret, ...)                                       \
    do {                                                                          \
        if (unlikely(!(a))) {                                                     \
            ESP_LOGE(TAG, "%s(%d): " msg, __FUNCTION__, __LINE__, ##__VA_ARGS__); \
            ret_code = ret;                                                       \
            goto tag;                                                             \
        }                                                                         \
    } while (0)

#define EC11_PCNT_DEFAULT_HIGH_LIMIT (360)
#define EC11_PCNT_DEFAULT_LOW_LIMIT  (0)

// A flag to identify if pcnt isr service has been installed.
static bool is_pcnt_isr_service_installed = false;
// A lock to avoid pcnt isr service being installed twice in multiple threads.
static _lock_t isr_service_install_lock;
#define LOCK_ACQUIRE() _lock_acquire(&isr_service_install_lock)
#define LOCK_RELEASE() _lock_release(&isr_service_install_lock)

typedef struct {
    int accumu_count;
    rotary_encoder_t parent;
    pcnt_unit_t pcnt_unit;
} ec11_t;

static esp_err_t ec11_set_glitch_filter(rotary_encoder_t *encoder, uint32_t max_glitch_us)
{
    esp_err_t ret_code = ESP_OK;
    ec11_t *ec11 = __containerof(encoder, ec11_t, parent);

    /* Configure and enable the input filter */
    ROTARY_CHECK(pcnt_set_filter_value(ec11->pcnt_unit, max_glitch_us * 80) == ESP_OK, "set glitch filter failed", err, ESP_FAIL);

    if (max_glitch_us) {
        pcnt_filter_enable(ec11->pcnt_unit);
    } else {
        pcnt_filter_disable(ec11->pcnt_unit);
    }

    return ESP_OK;
err:
    return ret_code;
}

static esp_err_t ec11_start(rotary_encoder_t *encoder)
{
    ec11_t *ec11 = __containerof(encoder, ec11_t, parent);
    pcnt_counter_resume(ec11->pcnt_unit);
    return ESP_OK;
}

static esp_err_t ec11_stop(rotary_encoder_t *encoder)
{
    ec11_t *ec11 = __containerof(encoder, ec11_t, parent);
    pcnt_counter_pause(ec11->pcnt_unit);
    return ESP_OK;
}

static int ec11_get_counter_value(rotary_encoder_t *encoder)
{
    ec11_t *ec11 = __containerof(encoder, ec11_t, parent);
    int16_t val = 0;
    pcnt_get_counter_value(ec11->pcnt_unit, &val);
    return val + ec11->accumu_count;
}

static esp_err_t ec11_del(rotary_encoder_t *encoder)
{
    ec11_t *ec11 = __containerof(encoder, ec11_t, parent);
    free(ec11);
    return ESP_OK;
}

static void ec11_pcnt_overflow_handler(void *arg)
{
    ec11_t *ec11 = (ec11_t *)arg;
    uint32_t status = 0;
    pcnt_get_event_status(ec11->pcnt_unit, &status);

    if (status & PCNT_EVT_H_LIM) {
        ec11->accumu_count += EC11_PCNT_DEFAULT_HIGH_LIMIT;
    } else if (status & PCNT_EVT_L_LIM) {
        ec11->accumu_count += EC11_PCNT_DEFAULT_LOW_LIMIT;
    }
}

esp_err_t rotary_encoder_new_ec11(const rotary_encoder_config_t *config, rotary_encoder_t **ret_encoder)
{
    esp_err_t ret_code = ESP_OK;
    ec11_t *ec11 = NULL;

    ROTARY_CHECK(config, "configuration can't be null", err, ESP_ERR_INVALID_ARG);
    ROTARY_CHECK(ret_encoder, "can't assign context to null", err, ESP_ERR_INVALID_ARG);

    ec11 = calloc(1, sizeof(ec11_t));
    ROTARY_CHECK(ec11, "allocate context memory failed", err, ESP_ERR_NO_MEM);

    ec11->pcnt_unit = (pcnt_unit_t)(config->dev);

    // Configure channel 0
    pcnt_config_t dev_config = {
        .pulse_gpio_num = config->phase_a_gpio_num,
        .ctrl_gpio_num = config->phase_b_gpio_num,
        .channel = PCNT_CHANNEL_0,
        .unit = ec11->pcnt_unit,
        .pos_mode = PCNT_COUNT_DEC,
        .neg_mode = PCNT_COUNT_INC,
        .lctrl_mode = PCNT_MODE_REVERSE,
        .hctrl_mode = PCNT_MODE_KEEP,
        .counter_h_lim = EC11_PCNT_DEFAULT_HIGH_LIMIT,
        .counter_l_lim = EC11_PCNT_DEFAULT_LOW_LIMIT,
    };
    ROTARY_CHECK(pcnt_unit_config(&dev_config) == ESP_OK, "config pcnt channel 0 failed", err, ESP_FAIL);

    // Configure channel 1
    dev_config.pulse_gpio_num = config->phase_b_gpio_num;
    dev_config.ctrl_gpio_num = config->phase_a_gpio_num;
    dev_config.channel = PCNT_CHANNEL_1;
    dev_config.pos_mode = PCNT_COUNT_INC;
    dev_config.neg_mode = PCNT_COUNT_DEC;
    ROTARY_CHECK(pcnt_unit_config(&dev_config) == ESP_OK, "config pcnt channel 1 failed", err, ESP_FAIL);

    // PCNT pause and reset value
    pcnt_counter_pause(ec11->pcnt_unit);
    pcnt_counter_clear(ec11->pcnt_unit);


    // register interrupt handler in a thread-safe way
    LOCK_ACQUIRE();
    if (!is_pcnt_isr_service_installed) {
        ROTARY_CHECK(pcnt_isr_service_install(0) == ESP_OK, "install isr service failed", err, ESP_FAIL);
        // make sure pcnt isr service won't be installed more than one time
        is_pcnt_isr_service_installed = true;
    }
    LOCK_RELEASE();

    pcnt_isr_handler_add(ec11->pcnt_unit, ec11_pcnt_overflow_handler, ec11);

    pcnt_event_enable(ec11->pcnt_unit, PCNT_EVT_H_LIM);
    pcnt_event_enable(ec11->pcnt_unit, PCNT_EVT_L_LIM);

    ec11->parent.del = ec11_del;
    ec11->parent.start = ec11_start;
    ec11->parent.stop = ec11_stop;
    ec11->parent.set_glitch_filter = ec11_set_glitch_filter;
    ec11->parent.get_counter_value = ec11_get_counter_value;

    *ret_encoder = &(ec11->parent);
    return ESP_OK;
err:
    if (ec11) {
        free(ec11);
    }
    return ret_code;
}

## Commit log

2022-11-19 Adding all the things.
    [spinner.kicad_pcb, spinner.kicad_sch]
2022-11-19 IDK. Add the kitchen sink.
    [spinner.kicad_pcb, spinner.kicad_sch]
2022-12-16 Update things. Next checkin.
    [spinner.kicad_pcb, spinner.kicad_sch]
2022-12-30 Adding all kinds of things.
    [spinner.kicad_pcb, spinner.step]
2023-01-07 Adding the BOM and more backups and updates to kicad files.
    [Spinner_BOM.csv, spinner.kicad_sch]
2023-01-17 Update schematice, etc, etc.
2023-02-03 Add code that may or may not work, for LEDs!!
2023-03-24 Updated schematic and things. For spin 2. And board layout.
    [spinner.kicad_pcb, spinner.kicad_sch]
2023-03-31 Adding the rod_bracket that holds the spinner to spin.
    [rod_bracket_01.g, rod_bracket_01.stl]
2023-03-31 Add STL folder, add crown and rod bracket.
    [crown_01.stl, rod_bracket_01.g, rod_bracket_01.stl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]
2023-04-25 Add crown with supports.
    [crown_w_supports.stl]
2023-08-18 Adding things: SD card, resistor pack, routing. Totally done.
    Issue: HKZ-563
    Changelog: No Functional Change.
    [spinner.kicad_pcb, spinner.kicad_sch]
2023-08-25 Adding the FINAL version (final_01_A_REAL_FINAL). V2
    [spinner.kicad_pcb]
2024-01-30 SPI turns on the lights.
2024-02-02 Make the lEDs go in color.
2024-02-04 Adding a rotary encoder lib.
2024-02-04 Revert "Adding a rotary encoder lib."
    This is hitting an assert on the interrupt.
    Docs say its for idf 3.3, I'm using 4.4
    This reverts commit 7da6d3bf328103cd7d3aabb0c6c265cfe1c53036.
    [main.c]
2024-02-04 Using 4.4 version of PCNT rotary encoder.
2024-02-10 Did some things. Without the print, it looked like it workt.
2024-04-19 Add ability to read image off card. Also ability to crash.
    [main.c, sd.c]
2024-04-26 Switch files and display every 500 ms.
2024-05-10 Oh sorrows... this week failed a bit. Can't read index.html
    [main.c, sd.c]
2024-09-27 Added interrupt for zero refletor thing.
    and apparently kicad thing as well.
2024-10-18 Add the SK8922 footprint.
2024-10-18 Committing things for test segment board.
    [segment_blinky.kicad_pcb, segment_blinky.kicad_sch]
2024-10-25 Add all the tings for the blinky tests & order it!!
    [blinky_bom.csv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]
2024-12-07 Start the mini version of the spinner.
    [spinner.kicad_pcb, spinner.kicad_sch]
2024-12-14 Place little LEDs into 3 rows.
    [segment_blinky.kicad_pcb, spinner.kicad_pcb]
2024-12-14 Place more LEDs. Not quite done.
    [spinner.kicad_pcb, spinner.kicad_sch]
2025-01-11 Push LEDs around and shrink board.
    Leaning towards using 3 14500 3.7v batteries.
    And figuring out on-board charging.
    [spinner.kicad_pcb]
